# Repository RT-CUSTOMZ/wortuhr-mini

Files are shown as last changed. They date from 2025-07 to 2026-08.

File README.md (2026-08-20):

# Einleitung

Kleinere Version der Original Campuswochen Wortuhr. 
Das Buchstabenlayout dieser WortUhr ist angelehnt an das Layout, welches von Frank Meyer verwendet wird.

Der Aufbau ist nun kompatibel mit 60 LED/m WS2812B/SK6812 LED Streifen. Um das zu erreichen ist die Rahmengröße reduziert auf 35cm Innenmaß. Hierzu eignet sich zum Beispiel der IKEA SANNAHED 35x35cm Rahmen. Die Steuerplatine ist auf das wesentliche beschränkt, die Stromversorgung übernehmen zwei generische DCDC Mini-560 Netzteile. Es wird weiterhin über einen Rundbuchsenanschluss mit 19-21V eingespeist. Um die Bestellung möglichst einfach zu gestalten werden die Power und Steuerplatine auf eine gemeinsame Platine gepaneled. (Siehe Kombiplatine THT)

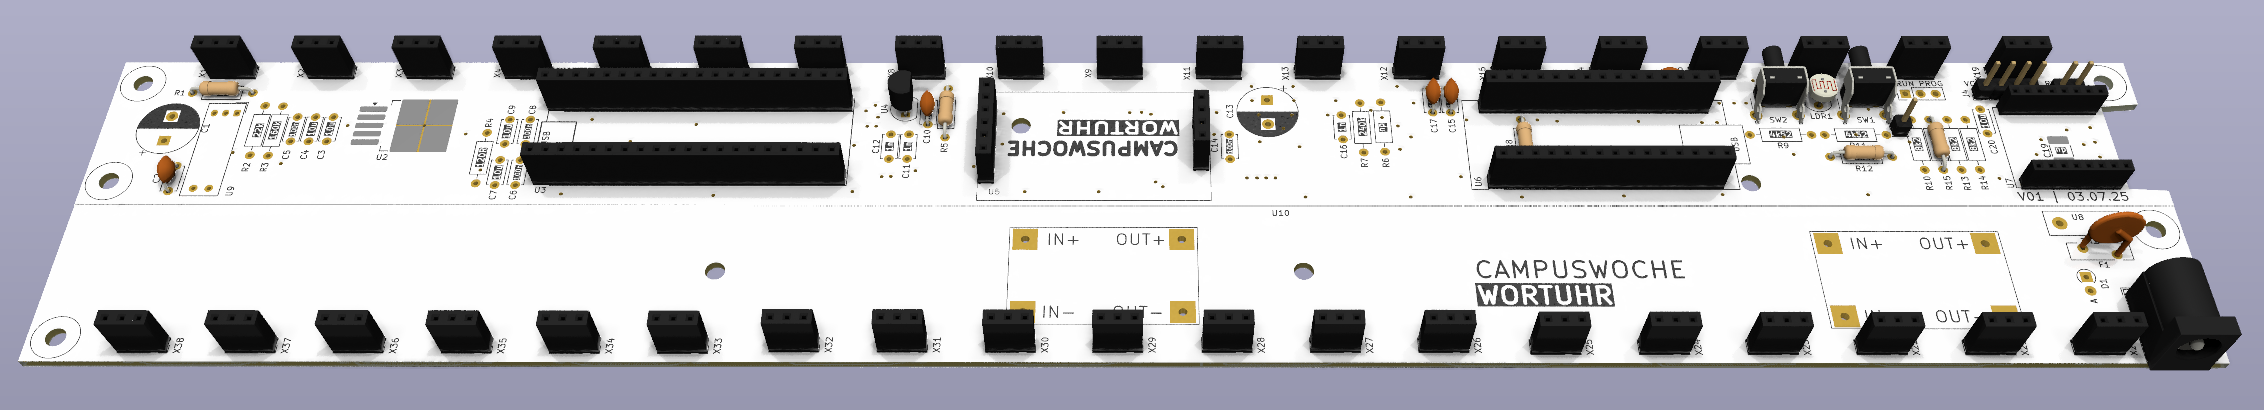
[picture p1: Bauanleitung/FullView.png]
Kombilatine


Die Software und das Layout der Matrix von Frank Meyer wurden minimal angepasst.

Originaler Artikel: https://www.mikrocontroller.net/articles/WordClock_mit_WS2812

Originaler Aufbau: https://www.mikrocontroller.net/articles/Tutorial_-_Aufbau_WordClock_mit_WS2812

# Inhaltsverzeichnis
- [Wiki](https://github.com/RT-CUSTOMZ/wortuhr-mini/wiki)
- [Bauanleitung]([/wiki/Bauanleitung](https://github.com/RT-CUSTOMZ/wortuhr-mini/wiki/Bauanleitung))
- [Hardware](https://github.com/RT-CUSTOMZ/wortuhr-mini/wiki/Hardware-Material)
- [Software](https://github.com/RT-CUSTOMZ/wortuhr-mini/wiki/Software)

Copyright (c) 2014-2019 Frank Meyer - frank(at)fli4l.de

This program is free software; you can redistribute it and/or modify it under the terms of the GNU General Public License as published by the Free Software Foundation; either version 2 of the License, or (at your option) any later version.

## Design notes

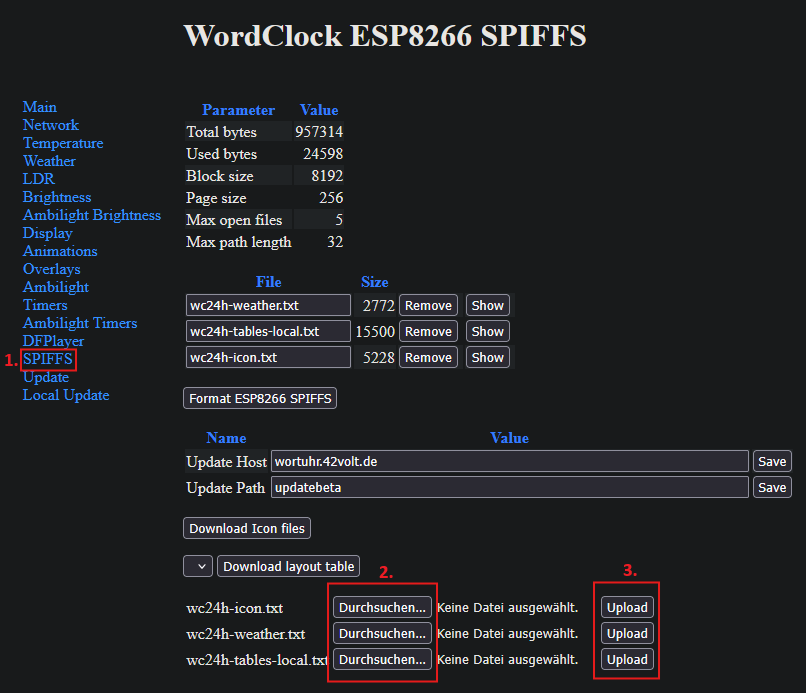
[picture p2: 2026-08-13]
Bilder/Finales_Einrichten/Wordclock_config-files.png

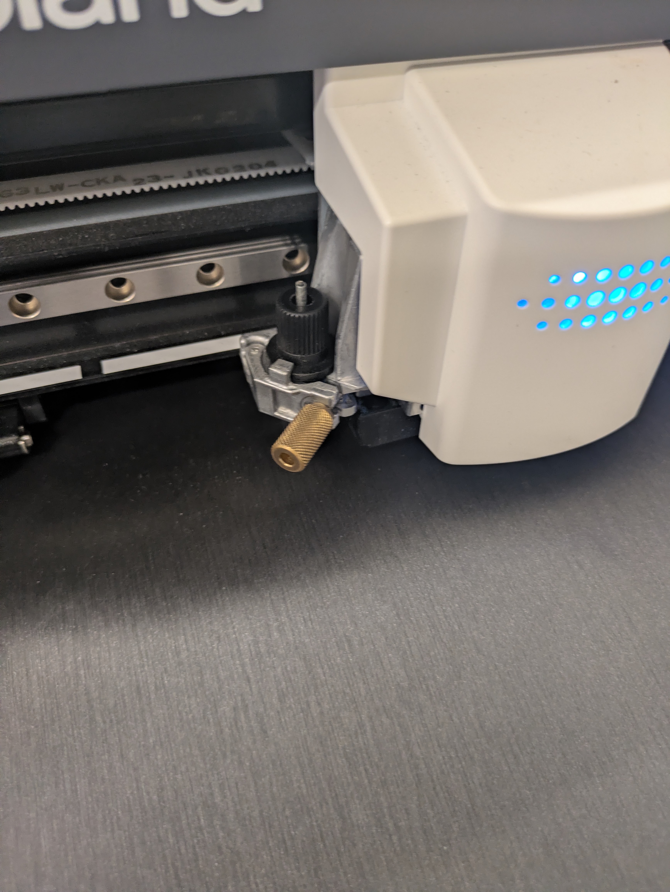
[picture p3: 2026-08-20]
Bilder/Plottern/2Klingeeinlegen.jpg

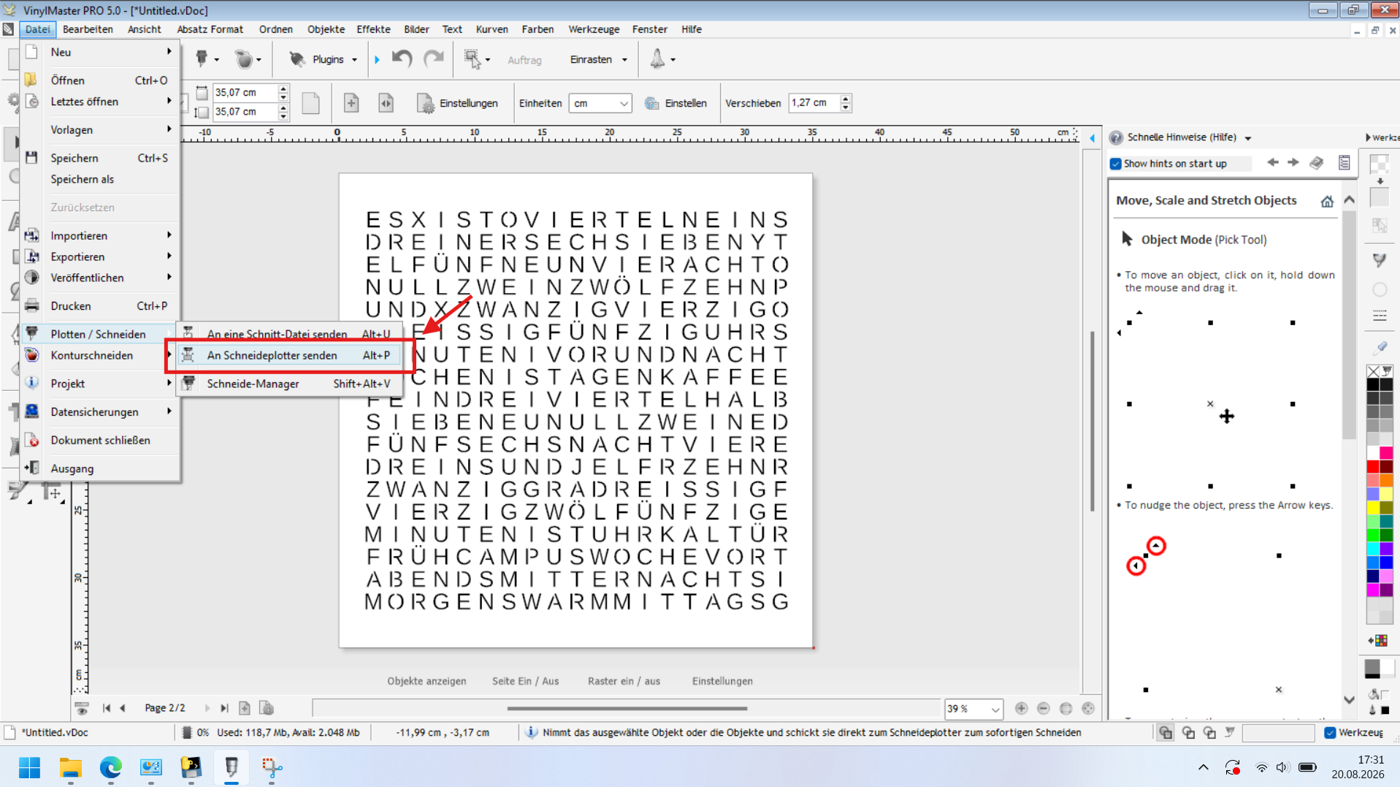
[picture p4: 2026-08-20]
Bilder/Plottern/17Plottern_6.png

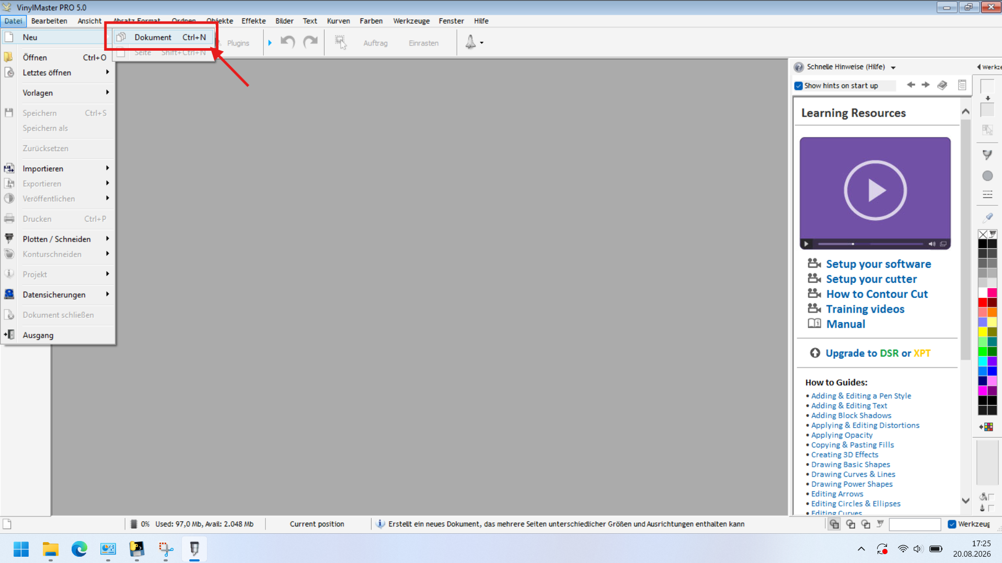
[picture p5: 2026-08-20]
Bilder/Plottern/14Plottern_3.png

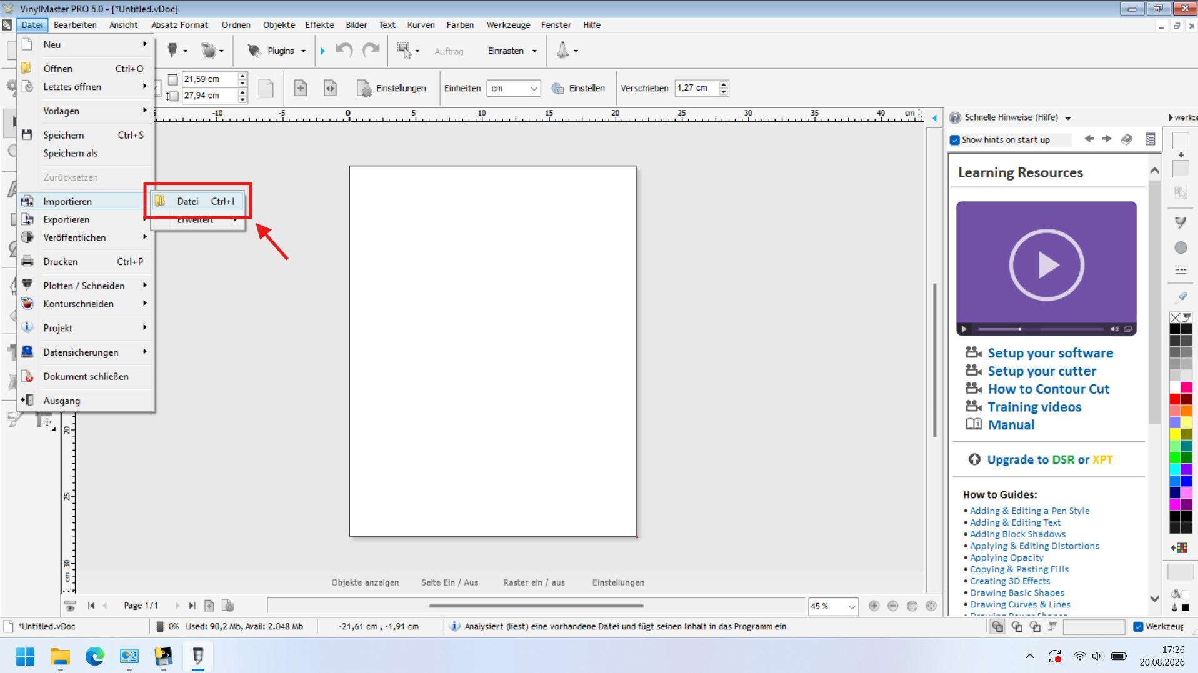
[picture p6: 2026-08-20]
Bilder/Plottern/15Plottern_4.png

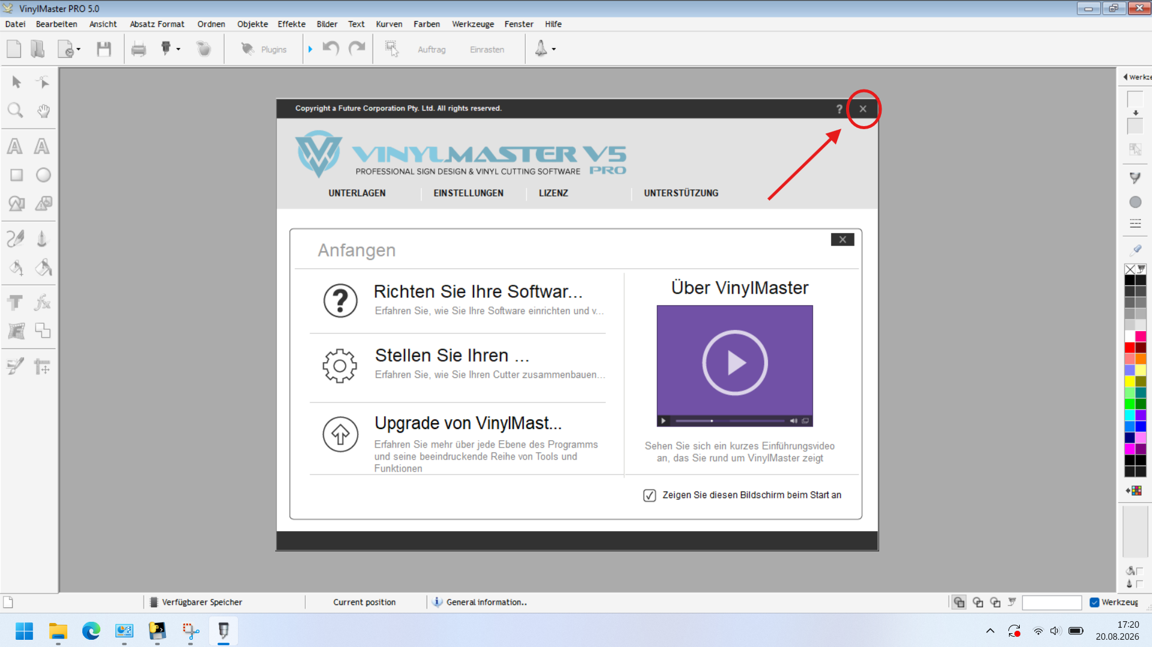
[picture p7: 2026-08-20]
Bilder/Plottern/13Plottern_2.png

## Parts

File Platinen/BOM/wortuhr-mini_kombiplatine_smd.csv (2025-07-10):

ID | Bezeichner | Footprint | Stückzahl | Bezeichnung | Anbieter und Referenz
1 | C19 | C_1812_4532Metric_Pad1.57x3.40mm_HandSolder | 1 | np | -
2 | SW1,SW2 | SW_Tactile_SPST_Angled_PTS645Vx83-2LFS | 2 | PTS645Vx83-2LFS | https://www.mouser.de/ProductDetail/CK/PTS645VL83-2-LFS?qs=rqnA19JZHeTMBWXURLIBsQ%3D%3D
3 | R4 | R_Axial_DIN0207_L6.3mm_D2.5mm_P10.16mm_Horizontal | 1 | 120R
4 | C1,C13 | CP_Radial_D10.0mm_P5.00mm | 2 | 47u
5 | U2 | TO-263-5_TabPin3 | 1 | MCP1826-ADJE/ET
6 | C3,C4,C20,C9,C7 | C_Disc_D4.7mm_W2.5mm_P5.00mm | 5 | 10u
7 | C5,C17,C14,C15,C8,C6,C2,C10,C18 | C_Disc_D4.7mm_W2.5mm_P5.00mm | 9 | 100n/X7R | https://www.mouser.de/ProductDetail/Vishay-BC-Components/K104M10X7RF5TH5?qs=ZjM2s42DDya77A69h%2FjzHg%3D%3D
8 | R2 | R_Axial_DIN0207_L6.3mm_D2.5mm_P10.16mm_Horizontal | 1 | 22k | 22k Metallschicht 1/4 Watt, 6,5mm, axial
9 | R3 | R_Axial_DIN0207_L6.3mm_D2.5mm_P10.16mm_Horizontal | 1 | 160k | 160k Metallschicht 1/4 Watt, 6,5mm, axial
10 | R12,R14,R10,R13,R5 | R_Axial_DIN0207_L6.3mm_D2.5mm_P10.16mm_Horizontal | 5 | 8k2
11 | R9,R11 | R_Axial_DIN0207_L6.3mm_D2.5mm_P10.16mm_Horizontal | 2 | 4K53
12 | J1 | TestPoint_Pad_1.0x1.0mm | 1 | Conn_01x01_Pin | -
13 | J3 | PinHeader_1x02_P2.54mm_Vertical | 1 | UART FLOATING | -
14 | X5,X4,X1,X7,X17,X3,X18,X14,X8,X16,X12,X10,X6,X13,X2,X9,X11,X15,X19 | PinHeader_1x03_P2.54mm_Vertical | 19 | Conn_01x03_Pin | https://www.mouser.de/ProductDetail/Preci-dip/801-87-010-53-001101?qs=q5BRkYolQ3jHhHUKXrMBBA%3D%3D
15 | U6 | Arduino_Nano | 1 | Arduino_Nano_Every
16 | U5 | DS3231 Module | 1 | ~ | https://eckstein-shop.de/RTC-Modul-mit-DS3231M-oder-DS3231SN-AT24C32-I2C-Echtzeituhr-mit-Batterie-fuer-Arduino-Raspberry-Pi
17 | R1,R6 | R_Axial_DIN0207_L6.3mm_D2.5mm_P10.16mm_Horizontal | 2 | np | -
18 | R8 | R_Axial_DIN0207_L6.3mm_D2.5mm_P10.16mm_Horizontal | 1 | 100k | 100k Metallschicht 1/4 Watt, 6,5mm, axial
19 | J2 | PinHeader_1x03_P2.54mm_Vertical | 1 | PROG MODE | -
20 | C16,C11,C12 | C_Disc_D4.7mm_W2.5mm_P5.00mm | 3 | 1nF/X7R | https://www.mouser.de/ProductDetail/Vishay-BC-Components/K102K15X7RF5UL2?qs=jPcpbI%252BG3FVUWYXRx4IYpg%3D%3D
21 | U7 | ESP-07 | 1 | ESP-12F | https://www.az-delivery.de/en/products/esp8266-12e
22 | U1 | DIP-6_W7.62mm_Socket_LongPads | 1 | H11L1 | https://www.mouser.de/ProductDetail/Adam-Tech/ICS-306-T?qs=FG09h9tFCuB6nMjq34Whag%3D%3D
 |  |  |  |  | https://www.mouser.de/ProductDetail/onsemi-Fairchild/H11L1TVM?qs=CaO7pQPYUzN4Nhr0JH3IIg%3D%3D
23 | U4 | TO-92_Inline | 1 | DS18B20 | https://www.reichelt.de/de/de/shop/produkt/digital_thermometer_1-wire_-_0_5_c_to-92-58169
24 | R7 | R_Axial_DIN0207_L6.3mm_D2.5mm_P10.16mm_Horizontal | 1 | 240k | 240k Metallschicht 1/4 Watt, 6,5mm, axial
25 | R15 | R_Axial_DIN0207_L6.3mm_D2.5mm_P10.16mm_Horizontal | 1 | 91R
26 | LDR1 | R_LDR_4.9x4.2mm_P2.54mm_Vertical | 1 | A 905014
27 | U3 | Bluepill | 1 | Bluepill | https://www.amazon.de/STM32F103C8T6-Minimum-Development-Learning-Importiertem/dp/B0B6BQSTSZ
 |  |  |  |  | https://www.mouser.de/ProductDetail/STMicroelectronics/STM32F103C8T6?qs=bhCVus9SdFtq6kqxsU5%2FDA%3D%3D
28 | J4 | PinHeader_1x04_P2.54mm_Vertical | 1 | UART | https://www.mouser.de/ProductDetail/Amphenol-FCI/10129378-916001BLF?qs=0lQeLiL1qybYnH80ih0s8Q%3D%3D
 |  | Netzteil Buchse |  |  | https://www.reichelt.de/de/de/shop/produkt/hohlstecker_knickschutz_aussen_5_5_mm_innen_2_1_mm-8647
 |  | DCDC Versorgung |  |  | https://www.az-delivery.de/en/products/spannungswandler-5a-8-36v-zu-1-25-32v?variant=6127498887195
 |  | LEDs |  |  | https://www.az-delivery.de/en/products/ws2812b-60-leds-m-60-pixels-m-led-strip-rgb-adressierbarer-led-streifen-mit-5050-smd-leds-ip20-schwarz-nicht-wasserdich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

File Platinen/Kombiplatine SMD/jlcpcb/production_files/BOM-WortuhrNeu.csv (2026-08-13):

Comment | Designator | Footprint | LCSC | Quantity
8k2 | R12 | R_0805_2012Metric_Pad1.20x1.40mm_HandSolder |  | 1
PTS645Vx83-2LFS | SW2 | SW_Tactile_SPST_Angled_PTS645Vx83-2LFS |  | 1
4K53 | R9 | R_0805_2012Metric_Pad1.20x1.40mm_HandSolder |  | 1
Conn_01x03_Pin | X38 | Pad LED Strip 1x03 2.54 |  | 1
Conn_01x01_Pin | J1 | PinHeader_1x01_P1.00mm_Vertical |  | 1
10u | C3 | C_1206_3216Metric_Pad1.33x1.80mm_HandSolder |  | 1
UART FLOATING | J3 | SolderJumper-2_P1.3mm_Open_RoundedPad1.0x1.5mm |  | 1
Conn_01x03_Pin | X5 | PinSocket_1x03_P2.54mm_Vertical |  | 1
10u | C4 | C_1206_3216Metric_Pad1.33x1.80mm_HandSolder |  | 1
10u | C20 | C_1206_3216Metric_Pad1.33x1.80mm_HandSolder |  | 1
100n/X7R | C17 | C_0805_2012Metric_Pad1.18x1.45mm_HandSolder |  | 1
MF-RHT100 | F1 | Fuse_Bourns_MF-RHT100 |  | 1
Arduino_Nano_Every | U6 | Arduino_Nano |  | 1
Conn_01x03_Pin | X23 | Pad LED Strip 1x03 2.54 |  | 1
Conn_01x03_Pin | X31 | Pad LED Strip 1x03 2.54 |  | 1
~ | U5 | DS3231 Module |  | 1
np | R1 | R_0805_2012Metric_Pad1.20x1.40mm_HandSolder |  | 1
Conn_01x03_Pin | X28 | Pad LED Strip 1x03 2.54 |  | 1
np | R6 | R_0805_2012Metric_Pad1.20x1.40mm_HandSolder |  | 1
Conn_01x03_Pin | X4 | PinSocket_1x03_P2.54mm_Vertical |  | 1
SL121R308 | TH1 | C_Disc_D12.0mm_W4.4mm_P7.75mm |  | 1
Conn_01x03_Pin | X1 | PinSocket_1x03_P2.54mm_Vertical |  | 1
Conn_01x03_Pin | X34 | Pad LED Strip 1x03 2.54 |  | 1
100k | R8 | R_0805_2012Metric_Pad1.20x1.40mm_HandSolder |  | 1
Conn_01x03_Pin | X7 | PinSocket_1x03_P2.54mm_Vertical |  | 1
8k2 | R14 | R_0805_2012Metric_Pad1.20x1.40mm_HandSolder |  | 1
Conn_01x03_Pin | X17 | PinSocket_1x03_P2.54mm_Vertical |  | 1
np | C19 | C_1206_3216Metric_Pad1.33x1.80mm_HandSolder |  | 1
PROG MODE | J2 | SolderJumper-3_P1.3mm_Open_RoundedPad1.0x1.5mm |  | 1
160k | R3 | R_0805_2012Metric_Pad1.20x1.40mm_HandSolder |  | 1
47u | C13 | CP_Radial_D10.0mm_P5.00mm |  | 1
Conn_01x03_Pin | X24 | Pad LED Strip 1x03 2.54 |  | 1
8k2 | R10 | R_0805_2012Metric_Pad1.20x1.40mm_HandSolder |  | 1
Conn_01x03_Pin | X3 | PinSocket_1x03_P2.54mm_Vertical |  | 1
1N5822 | D1 | D_SMC |  | 1
100n/X7R | C14 | C_0805_2012Metric_Pad1.18x1.45mm_HandSolder |  | 1
Conn_01x03_Pin | X20 | Pad LED Strip 1x03 2.54 |  | 1
Eingangsbuchse | J5 | BarrelJack_GCT_DCJ200-10-A_Horizontal |  | 1
1nF/X7R | C16 | C_0805_2012Metric_Pad1.18x1.45mm_HandSolder |  | 1
Conn_01x03_Pin | X18 | PinSocket_1x03_P2.54mm_Vertical |  | 1
Conn_01x03_Pin | X29 | Pad LED Strip 1x03 2.54 |  | 1
Conn_01x03_Pin | X14 | PinSocket_1x03_P2.54mm_Vertical |  | 1
Conn_01x03_Pin | X8 | PinSocket_1x03_P2.54mm_Vertical |  | 1
100n/X7R | C15 | C_0805_2012Metric_Pad1.18x1.45mm_HandSolder |  | 1
PTS645Vx83-2LFS | SW1 | SW_Tactile_SPST_Angled_PTS645Vx83-2LFS |  | 1
Conn_01x03_Pin | X16 | PinSocket_1x03_P2.54mm_Vertical |  | 1
Conn_01x03_Pin | X12 | PinSocket_1x03_P2.54mm_Vertical |  | 1
ESP-07 | U7 | ESP-07 |  | 1
1nF/X7R | C11 | C_0805_2012Metric_Pad1.18x1.45mm_HandSolder |  | 1
Conn_01x03_Pin | X36 | Pad LED Strip 1x03 2.54 |  | 1
10u | C9 | C_1206_3216Metric_Pad1.33x1.80mm_HandSolder |  | 1
100n/X7R | C8 | C_0805_2012Metric_Pad1.18x1.45mm_HandSolder |  | 1
10u | C7 | C_1206_3216Metric_Pad1.33x1.80mm_HandSolder |  | 1
1nF/X7R | C12 | C_0805_2012Metric_Pad1.18x1.45mm_HandSolder |  | 1
4K53 | R11 | R_0805_2012Metric_Pad1.20x1.40mm_HandSolder |  | 1
Conn_01x03_Pin | X32 | Pad LED Strip 1x03 2.54 |  | 1
DS18B20 | U4 | TO-92_Inline |  | 1
100n/X7R | C6 | C_0805_2012Metric_Pad1.18x1.45mm_HandSolder |  | 1
Generic DCDC | U8 | Converter_DCDC_RECOM_R-78B-2.0_THT |  | 1
Conn_01x03_Pin | X10 | PinSocket_1x03_P2.54mm_Vertical |  | 1
Conn_01x03_Pin | X6 | PinSocket_1x03_P2.54mm_Vertical |  | 1
Conn_01x03_Pin | X27 | Pad LED Strip 1x03 2.54 |  | 1
Conn_01x03_Pin | X13 | PinSocket_1x03_P2.54mm_Vertical |  | 1
TP582 | U9 | TP582 |  | 1
Conn_01x03_Pin | X2 | PinSocket_1x03_P2.54mm_Vertical |  | 1
100n/X7R | C2 | C_0805_2012Metric_Pad1.18x1.45mm_HandSolder |  | 1
Conn_01x03_Pin | X9 | PinSocket_1x03_P2.54mm_Vertical |  | 1
240k | R7 | R_0805_2012Metric_Pad1.20x1.40mm_HandSolder |  | 1
Conn_01x03_Pin | X11 | PinSocket_1x03_P2.54mm_Vertical |  | 1
100n/X7R | C10 | C_0805_2012Metric_Pad1.18x1.45mm_HandSolder |  | 1
22k | R2 | R_0805_2012Metric_Pad1.20x1.40mm_HandSolder |  | 1
Conn_01x03_Pin | X33 | Pad LED Strip 1x03 2.54 |  | 1
91R | R15 | R_0805_2012Metric_Pad1.20x1.40mm_HandSolder |  | 1
Conn_01x03_Pin | X30 | Pad LED Strip 1x03 2.54 |  | 1
Conn_01x03_Pin | X26 | Pad LED Strip 1x03 2.54 |  | 1
Conn_01x03_Pin | X35 | Pad LED Strip 1x03 2.54 |  | 1
Conn_01x03_Pin | X15 | PinSocket_1x03_P2.54mm_Vertical |  | 1
Conn_01x03_Pin | X25 | Pad LED Strip 1x03 2.54 |  | 1
Conn_01x03_Pin | X19 | PinSocket_1x03_P2.54mm_Vertical |  | 1
47u | C1 | CP_Radial_D10.0mm_P5.00mm |  | 1
MCP1826-ADJE/ET | U2 | TO-263-5_TabPin3 |  | 1
8k2 | R13 | R_0805_2012Metric_Pad1.20x1.40mm_HandSolder |  | 1
100n/X7R | C18 | C_0805_2012Metric_Pad1.18x1.45mm_HandSolder |  | 1
8k2 | R5 | R_0805_2012Metric_Pad1.20x1.40mm_HandSolder |  | 1
Conn_01x03_Pin | X22 | Pad LED Strip 1x03 2.54 |  | 1
100n/X7R | C5 | C_0805_2012Metric_Pad1.18x1.45mm_HandSolder |  | 1
A 905014 | LDR1 | R_LDR_4.9x4.2mm_P2.54mm_Vertical |  | 1
Conn_01x03_Pin | X37 | Pad LED Strip 1x03 2.54 |  | 1
Bluepill | U3 | Bluepill |  | 1
120R | R4 | R_0805_2012Metric_Pad1.20x1.40mm_HandSolder |  | 1
Conn_01x03_Pin | X21 | Pad LED Strip 1x03 2.54 |  | 1
UART | J4 | PinHeader_1x04_P2.54mm_Vertical |  | 1

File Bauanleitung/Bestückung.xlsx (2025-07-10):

Column1 | Placed | References | Value | Quantity
1 |  | C2, C5, C6, C8, C10, C14, C15, C17, C18 | 100nF | 9
2 |  | C3, C4, C7, C9, C20 | 10uF | 5
3 |  | C11, C12, C16 | 1nF | 3
4 |  | C1, C13 | 47uF | 2
5 |  | R5, R10, R12, R13, R14 | 8,2kΩ | 5
6 |  | R9, R11 | 4,53kΩ | 2
7 |  | R2 | 22kΩ | 1
8 |  | R3 | 160kΩ | 1
9 |  | R4 | 120Ω | 1
10 |  | R7 | 240kΩ | 1
11 |  | R8 | 100kΩ | 1
12 |  | R15 | 91Ω | 1
13 |  | U1 | IC Sockel 6 polig, 2,54mm | 1
14 |  | U2 | MCP1826-ADJE/ET Spannungswandler | 1
15 |  | U3 | Buchsenleiste 1x20, 2,54mm | 2
16 |  | U4 | DS18B20 Temperatursensor | 1
17 |  | U5 | Buchsenleiste 1x4, 2,54mm | 2
18 |  | U7 | Buchsenleiste 1x8, 2mm | 2
19 |  | SW1, SW2 | Taster gewinkelt | 2
20 |  | LDR1 | A 905014 Helligkeitssensor | 1
21 |  | J2 | Stiftleiste 1x3, 2,54mm | 1
22 |  | J3 | Stiftleiste 1x2, 2,54mm | 1
23 |  | J4 | Stiftleiste 1x4, 2,54mm | 1
24 |  | X1, X2, X3, X4, X5, X6, X7, X8, X9, X10, X11, X12, X13, X14, X15, X16, X17, X18, X19 | Buchsenleiste 1x3, 2,54mm | 19

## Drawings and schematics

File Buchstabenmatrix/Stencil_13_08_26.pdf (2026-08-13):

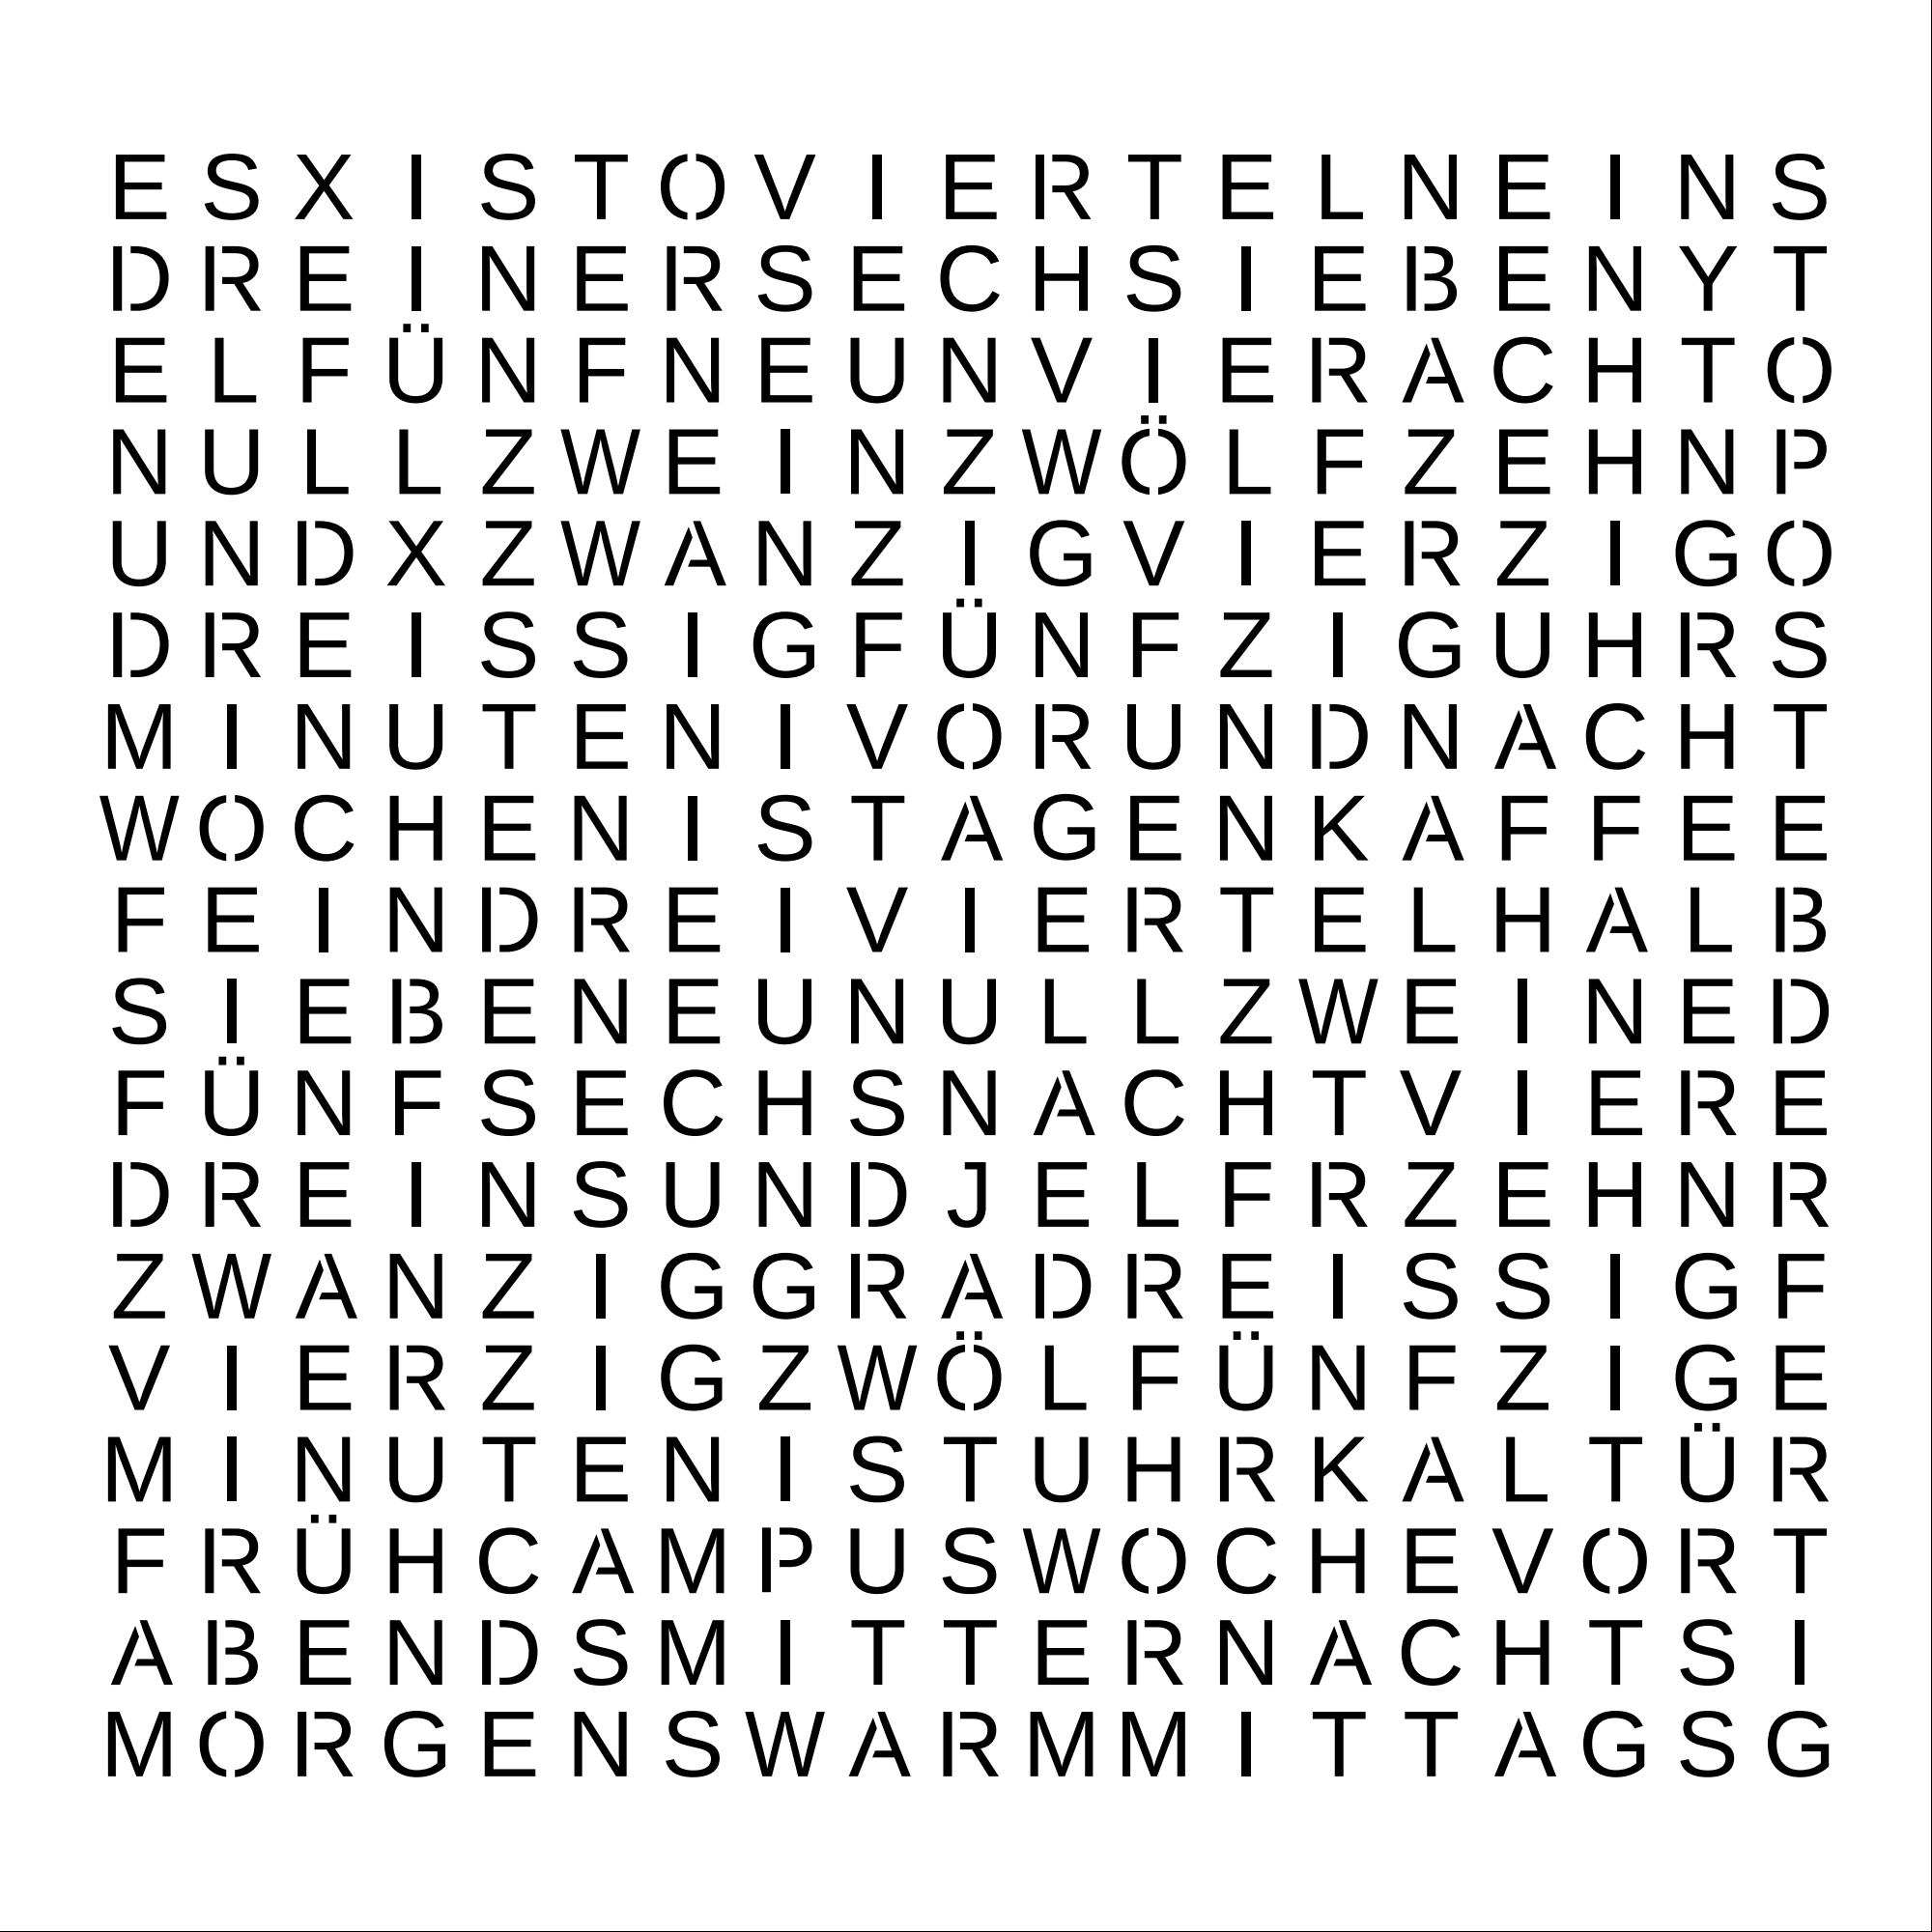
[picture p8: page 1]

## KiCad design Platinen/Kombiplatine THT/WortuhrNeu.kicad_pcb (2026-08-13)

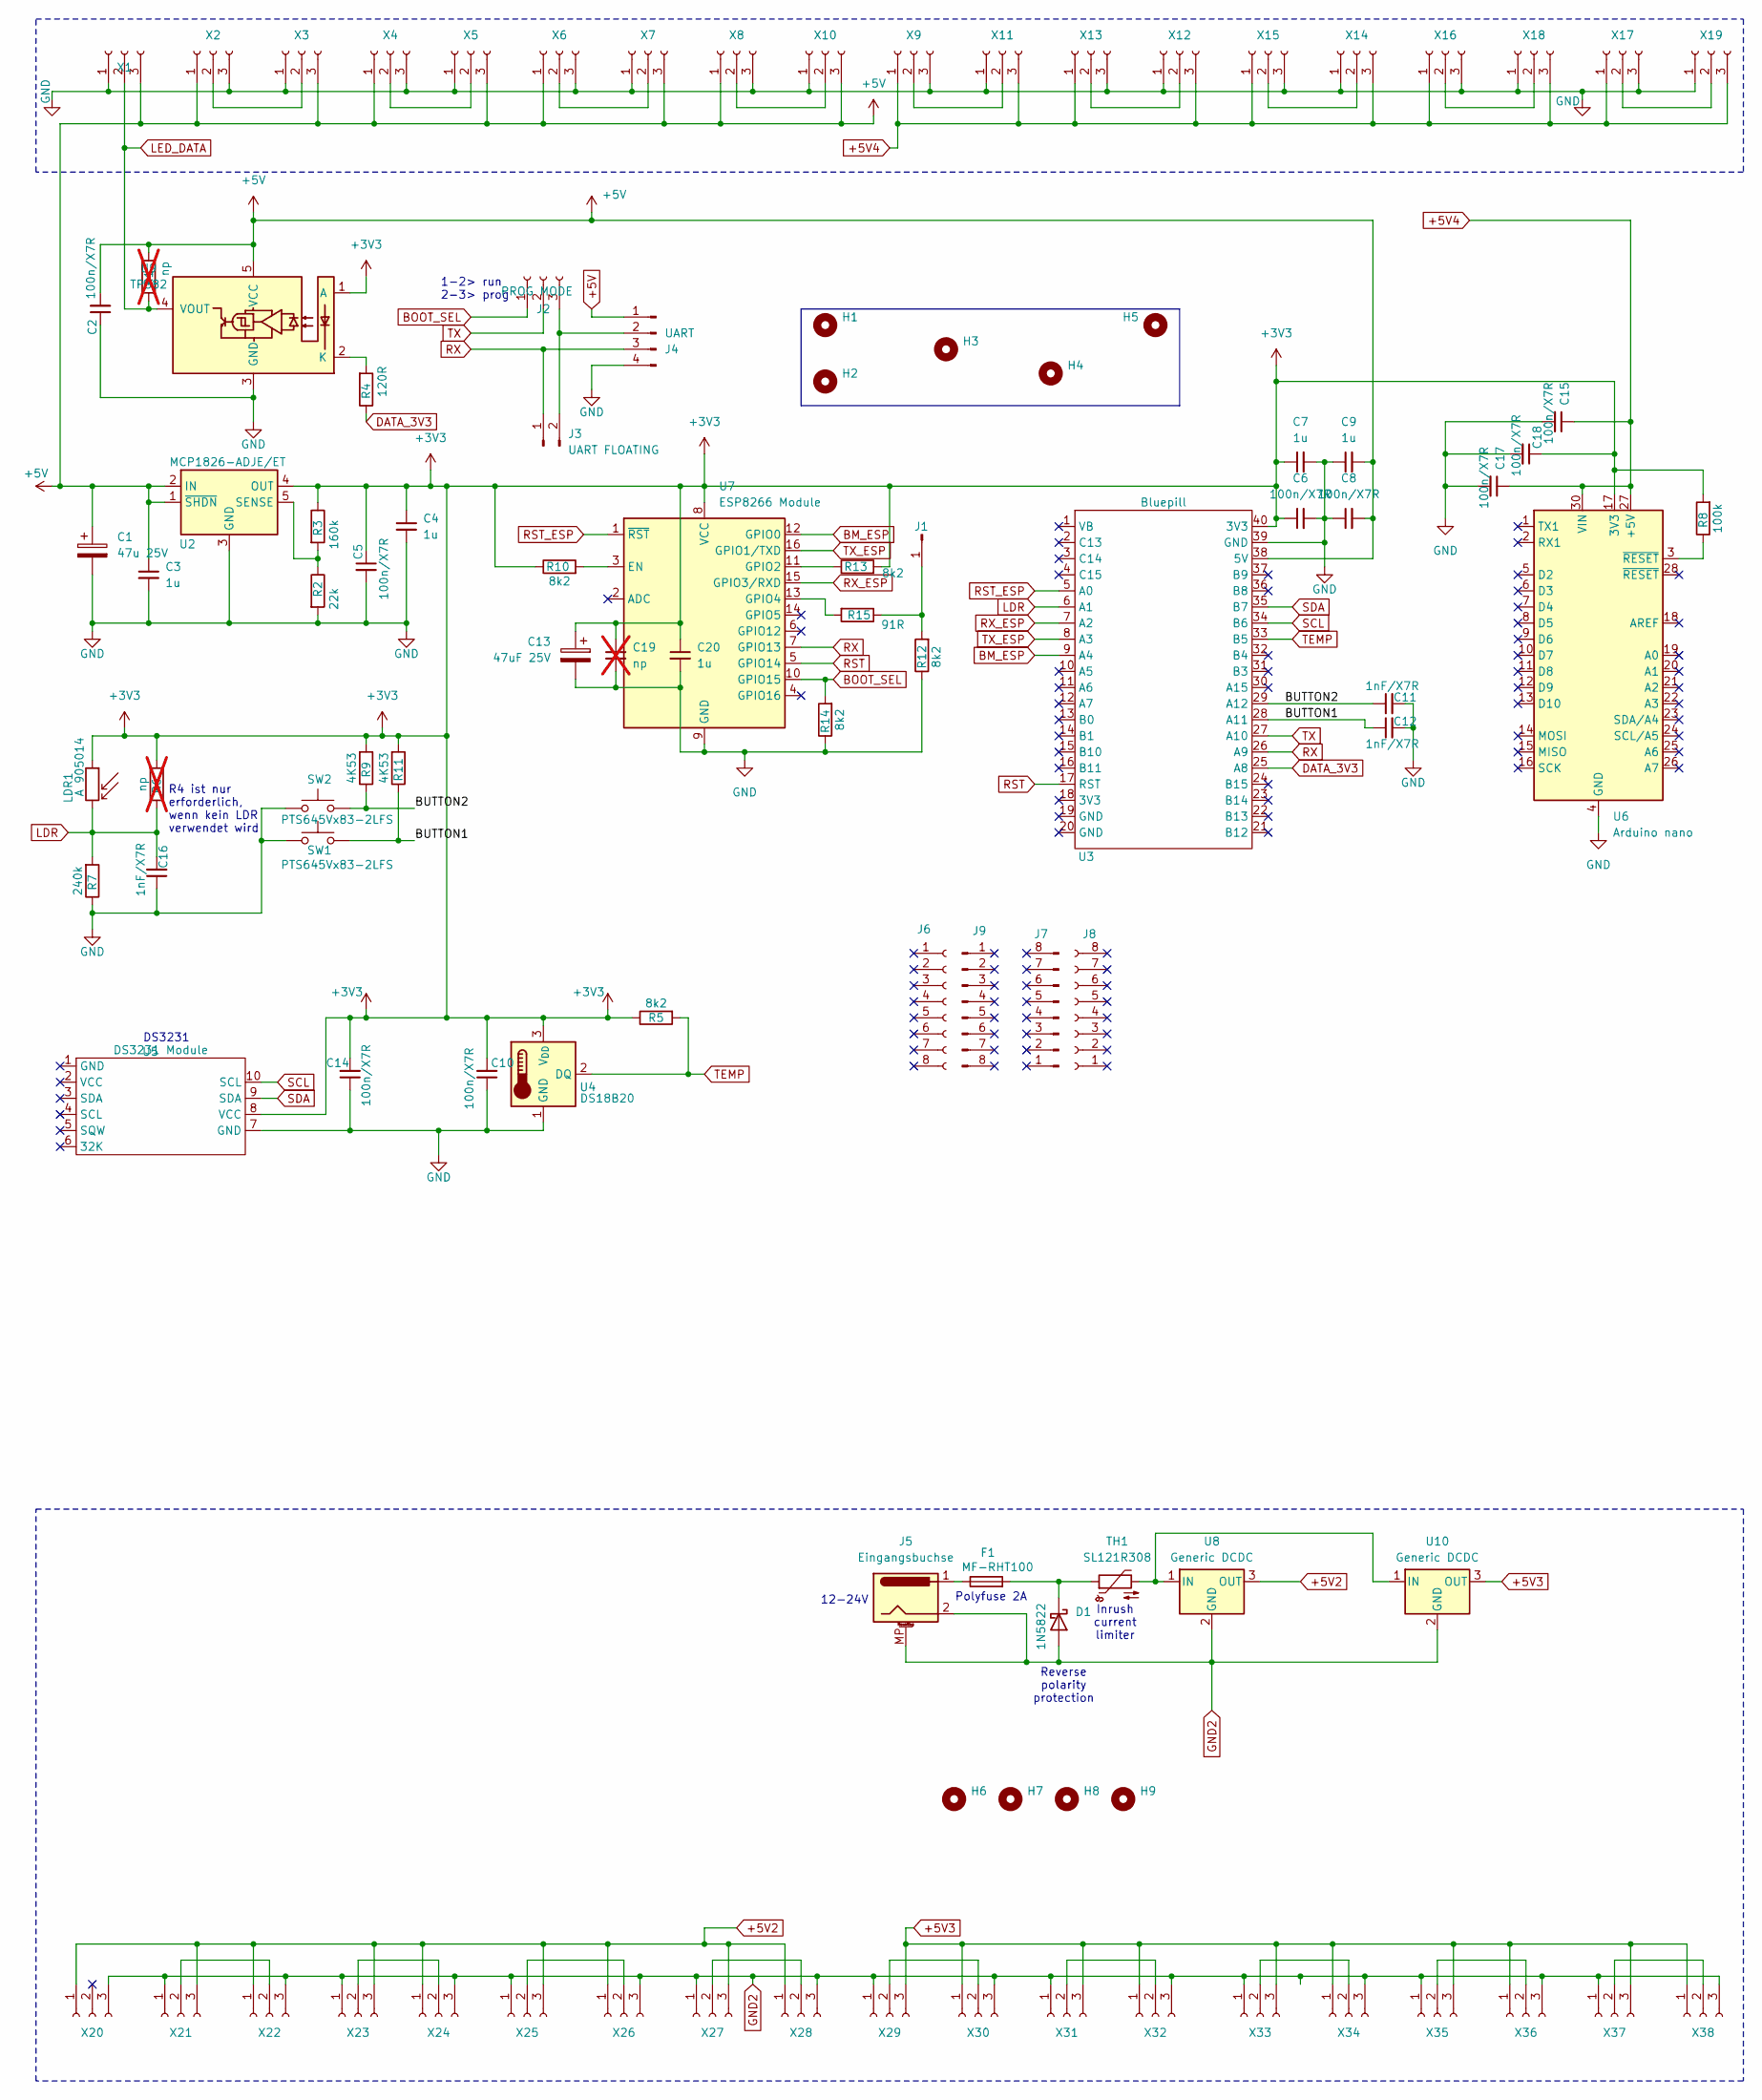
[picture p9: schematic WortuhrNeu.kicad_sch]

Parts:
C1: 47u 25V; CP_Radial_D10.0mm_P5.00mm
C2, C5, C6, C8, C10, C14, C15, C17, C18: 100n/X7R; C_Disc_D4.7mm_W2.5mm_P5.00mm
C3, C4, C7, C9, C20: 1u; C_Disc_D4.7mm_W2.5mm_P5.00mm
C11, C12, C16: 1nF/X7R; C_Disc_D4.7mm_W2.5mm_P5.00mm
C13: 47uF 25V; CP_Radial_D10.0mm_P5.00mm
C19: np; C_1812_4532Metric_Pad1.57x3.40mm_HandSolder; not fitted
D1: 1N5822; D_A-405_P2.54mm_Vertical_AnodeUp
F1: MF-RHT100; Fuse_Bourns_MF-RHT100
H1, H2, H3, H4, H5, H6, H7, H8, H9: MountingHole; MountingHole_3.2mm_M3_DIN965
J1: Conn_01x01_Pin; PinHeader_1x01_P2.54mm_Vertical
J2: PROG MODE; PinHeader_1x03_P2.54mm_Vertical
J3: UART FLOATING; PinHeader_1x02_P2.54mm_Vertical
J4: UART; PinHeader_1x04_P2.54mm_Vertical
J5: Eingangsbuchse; BarrelJack_GCT_DCJ200-10-A_Horizontal
J6, J7: Conn_01x08_Pin; PinHeader_1x08_P2.00mm_Vertical
J8, J9: Conn_01x08_Socket; PinSocket_1x08_P2.00mm_Vertical
LDR1: A 905014; R_LDR_4.9x4.2mm_P2.54mm_Vertical
R1, R6: np; R_Axial_DIN0207_L6.3mm_D2.5mm_P10.16mm_Horizontal; not fitted
R2: 22k; R_Axial_DIN0207_L6.3mm_D2.5mm_P10.16mm_Horizontal
R3: 160k; R_Axial_DIN0207_L6.3mm_D2.5mm_P10.16mm_Horizontal
R4: 120R; R_Axial_DIN0207_L6.3mm_D2.5mm_P10.16mm_Horizontal
R5, R10, R12, R13, R14: 8k2; R_Axial_DIN0207_L6.3mm_D2.5mm_P10.16mm_Horizontal
R7: 240k; R_Axial_DIN0207_L6.3mm_D2.5mm_P10.16mm_Horizontal
R8: 100k; R_Axial_DIN0207_L6.3mm_D2.5mm_P10.16mm_Horizontal
R9, R11: 4K53; R_Axial_DIN0207_L6.3mm_D2.5mm_P10.16mm_Horizontal
R15: 91R; R_Axial_DIN0207_L6.3mm_D2.5mm_P10.16mm_Horizontal
SW1, SW2: PTS645Vx83-2LFS; SW_Tactile_SPST_Angled_PTS645Vx83-2LFS
TH1: SL121R308; C_Disc_D12.0mm_W4.4mm_P7.75mm
U2: MCP1826-ADJE/ET; TO-263-5_TabPin3
U3: Bluepill
U4: DS18B20; TO-92_Inline
U5: DS3231 Module
U6: Arduino nano; Arduino_Nano
U7: ESP8266 Module; ESP-07
U8, U10: Generic DCDC; Converter_DCDC_RECOM_R-78B-2.0_THT
U9: TP582
X1, X2, X3, X4, X5, X6, X7, X8, X9, X10, X11, X12, X13, X14, X15, X16, X17, X18, X19, X20, X21, X22, X23, X24, X25, X26, X27, X28, X29, X30, X31, X32, X33, X34, X35, X36, X37, X38: Conn_01x03_Pin; PinSocket_1x03_P2.54mm_Vertical

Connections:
+3V3: C4.1, C5.1, C6.1, C7.1, C10.2, C13.1, C14.2, C18.1, C19.1, C20.1, LDR1.1, R3.1, R5.1, R6.2, R8.2, R9.2, R10.1, R11.2, R13.2, U2.4 (OUT), U3.40 (3V3), U4.3 (V_{DD}), U5.8 (VCC), U6.17 (3V3), U7.8 (VCC), U9.1 (A)
+5V: C1.1, C2.2, C3.1, C8.2, C9.2, J4.1, R1.2, U2.1 (~SHDN), U2.2 (IN), U3.38 (5V), U9.5 (VCC), X1.3, X2.1, X3.3, X4.1, X5.3, X6.1, X7.3, X8.1, X10.3
+5V2: U8.3 (OUT), X20.1, X21.3, X22.1, X23.3, X24.1, X25.3, X26.1, X27.3, X28.1
+5V3: U10.3 (OUT), X29.3, X30.1, X31.3, X32.1, X33.3, X34.1, X35.3, X36.1, X37.3, X38.1
+5V4: C15.1, C17.1, U6.27 (+5V), U6.30 (VIN), X9.1, X11.3, X12.3, X13.1, X14.3, X15.1, X16.1, X17.1, X18.3, X19.3
/BUTTON1: C12.1, R11.1, SW1.1, U3.28 (A11)
/BUTTON2: C11.1, R9.1, SW2.1, U3.29 (A12)
BM_ESP: U3.9 (A4), U7.12 (GPIO0)
BOOT_SEL: J2.1, R14.2, U7.10 (GPIO15)
DATA_3V3: R4.1, U3.25 (A8)
GND: C1.2, C2.1, C3.2, C4.2, C5.2, C6.2, C7.2, C8.1, C9.1, C10.1, C11.2, C12.2, C13.2, C14.1, C15.2, C16.1, C17.2, C18.2, C19.2, C20.2, J4.4, R2.2, R7.1, R12.1, R14.1, SW1.2, SW2.2, U2.3 (GND), U3.39 (GND), U4.1 (GND), U5.7 (GND), U6.4 (GND), U6.29 (GND), U7.9 (GND), U9.3 (GND), X1.1, X2.3, X3.1, X4.3, X5.1, X6.3, X7.1, X8.3, X9.3, X10.1, X11.1, X12.1, X13.3, X14.1, X15.3, X16.3, X17.3, X18.1, X19.1
GND2: D1.2 (A), J5.2, J5.MP (MountPin_MP), U8.2 (GND), U10.2 (GND), X20.3, X21.1, X22.3, X23.1, X24.3, X25.1, X26.3, X27.1, X28.3, X29.1, X30.3, X31.1, X32.3, X33.1, X34.3, X35.1, X36.3, X37.1, X38.3
LDR: C16.2, LDR1.2, R6.1, R7.2, U3.6 (A1)
LED_DATA: R1.1, U9.4 (VOUT), X1.2
unnamed: D1.1 (K), F1.2, TH1.1
unnamed: F1.1, J5.1
unnamed: J1.1 (Pin_1_1), R12.2, R15.1
unnamed: J2.3, J3.2, J4.2
unnamed: R8.1, U6.3 (~RESET)
unnamed: R2.1, R3.2, U2.5 (SENSE)
unnamed: R10.2, U7.3 (EN)
unnamed: R13.1, U7.11 (GPIO2)
unnamed: R15.2, U7.13 (GPIO4)
unnamed: R4.2, U9.2 (K)
unnamed: TH1.2, U8.1 (IN), U10.1 (IN)
unnamed: X2.2, X3.2
unnamed: X4.2, X5.2
unnamed: X6.2, X7.2
unnamed: X8.2, X10.2
unnamed: X9.2, X11.2
unnamed: X12.2, X13.2
unnamed: X14.2, X15.2
unnamed: X16.2, X18.2
unnamed: X17.2, X19.2
unnamed: X21.2, X22.2
unnamed: X23.2, X24.2
unnamed: X25.2, X26.2
unnamed: X27.2, X28.2
unnamed: X29.2, X30.2
unnamed: X31.2, X32.2
unnamed: X33.2, X34.2
unnamed: X35.2, X36.2
unnamed: X37.2, X38.2
RST: U3.17 (RST), U7.5 (GPIO14)
RST_ESP: U3.5 (A0), U7.1 (~RST)
RX: J3.1, J4.3, U3.26 (A9), U7.7 (GPIO13)
RX_ESP: U3.7 (A2), U7.15 (GPIO3/RXD)
SCL: U3.34 (B6), U5.10 (SCL)
SDA: U3.35 (B7), U5.9 (SDA)
TEMP: R5.2, U3.33 (B5), U4.2 (DQ)
TX: J2.2, U3.27 (A10)
TX_ESP: U3.8 (A3), U7.16 (GPIO1/TXD)

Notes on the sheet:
R4 ist nur erforderlich, wenn kein LDR verwendet wird
12-24V
DS3231
Polyfuse 2A
Reverse polarity protection
Inrush current limiter
1-2> run 2-3> prog

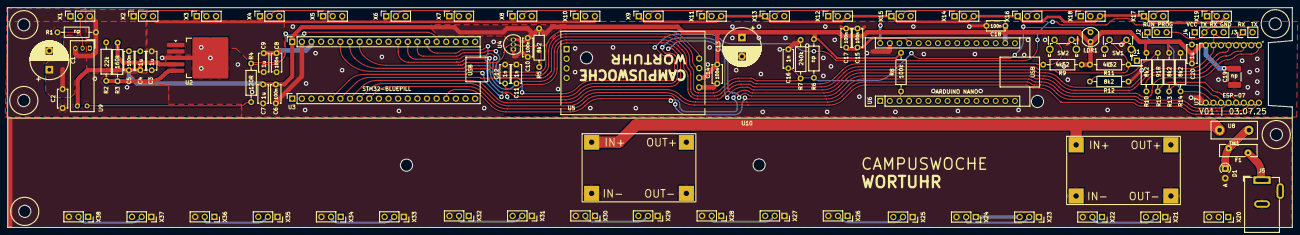
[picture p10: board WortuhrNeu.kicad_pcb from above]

Board: 2 copper layers, 339.0 x 58.0 mm, 102 parts (0 on the bottom side), 52 nets.

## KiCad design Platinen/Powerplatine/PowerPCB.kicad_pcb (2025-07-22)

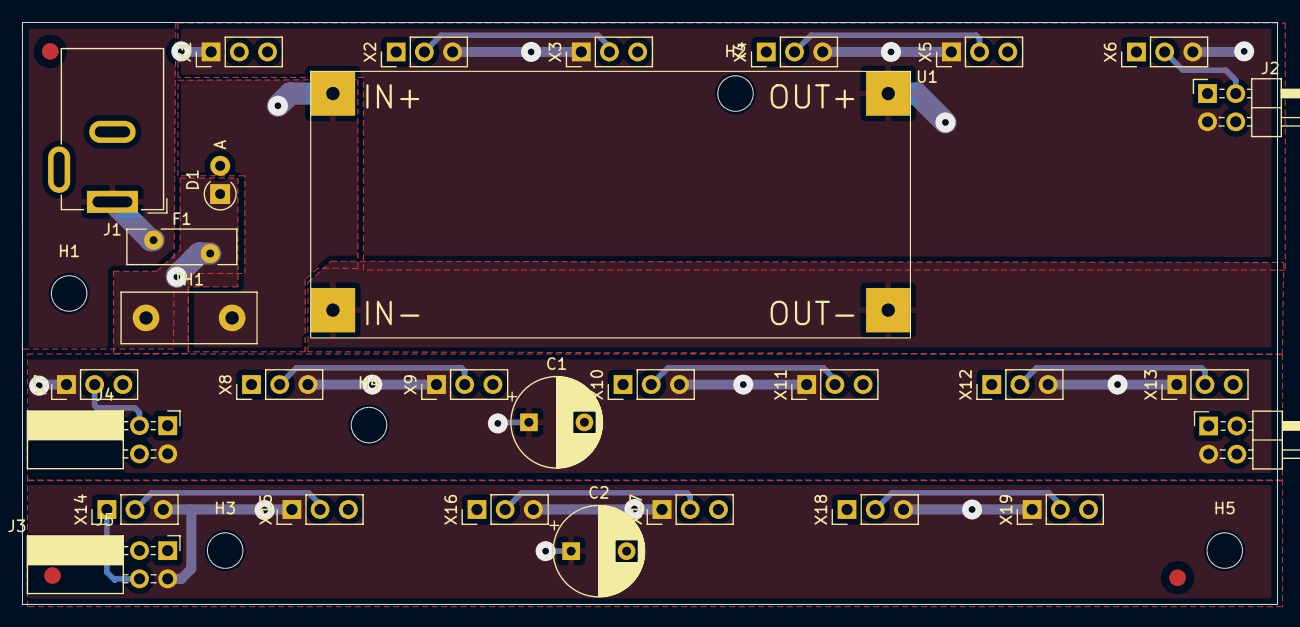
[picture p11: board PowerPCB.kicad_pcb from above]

Board: 2 copper layers, 113.0 x 52.4 mm, 38 parts (0 on the bottom side), 19 nets.

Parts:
C1, C2: 47u; CP_Radial_D8.0mm_P5.00mm
D1: 1N5822; D_A-405_P2.54mm_Vertical_AnodeUp
F1: MF-RHT100; Fuse_Bourns_MF-RHT100
FID1, FID2, FID3: Fiducial; Fiducial_1.5mm_Mask3mm
H1, H2, H3, H4, H5: MountingHole; MountingHole_3.2mm_M3_DIN965
J1: Eingangsbuchse; BarrelJack_GCT_DCJ200-10-A_Horizontal
J2, J3: Conn_01x03_Pin; PinHeader_2x02_P2.54mm_Horizontal
J4, J5: Conn_01x03_Socket; PinSocket_2x02_P2.54mm_Horizontal
TH1: SL121R308; C_Disc_D12.0mm_W4.4mm_P7.75mm
U1: Generic DCDC; Converter_DCDC_RECOM_R-78B-2.0_THT
X1, X2, X3, X4, X5, X6, X7, X8, X9, X10, X11, X12, X13, X14, X15, X16, X17, X18, X19: Conn_01x03_Pin; PinHeader_1x03_P2.54mm_Vertical

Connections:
+5V: J2.3, U1.3 (OUT), X1.1, X2.3, X3.1, X4.3, X5.1, X6.3
+5V2: C1.1, J3.3, J4.3, X7.1, X8.3, X9.1, X10.3, X11.1, X12.3, X13.1
+5V3: C2.1, J5.3, X14.3, X15.1, X16.3, X17.1, X18.3, X19.1
GND: D1.2 (A), J1.2, J1.MP (MountPin), J2.1, U1.2 (GND), X1.3, X2.1, X3.3, X4.1, X5.3, X6.1
GND2: C1.2, J3.1, J4.1, X7.3, X8.1, X9.3, X10.1, X11.3, X12.1, X13.3
GND3: C2.2, J5.1, X14.1, X15.3, X16.1, X17.3, X18.1, X19.3
unnamed: D1.1 (K), F1.2, TH1.1
unnamed: F1.1, J1.1
unnamed: J2.2, X6.2
unnamed: J4.2, X7.2
unnamed: TH1.2, U1.1 (IN)
unnamed: X2.2, X3.2
unnamed: X4.2, X5.2
unnamed: X8.2, X9.2
unnamed: X10.2, X11.2
unnamed: X12.2, X13.2
unnamed: X14.2, X15.2
unnamed: X16.2, X17.2
unnamed: X18.2, X19.2

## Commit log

2025-07-10 Changed file structure
    [WortuhrNeu.kicad_pcb, WortuhrNeu.kicad_sch]
2025-07-14 Added power PCB/protection circuits
    [PowerPCB.kicad_pcb, PowerPCB.kicad_sch, WortuhrNeu.kicad_pcb]
2025-07-14 Changed pins to sockets, added image
    [PowerPCB.kicad_pcb]
2025-07-14 added letter matrix pdf v1
    [PowerPCB.kicad_pcb, PowerPCB.kicad_sch, wortuhr-mini.csv]
2025-07-19 Adjusted letter matrix and added stencil verśion
    [PowerPCB-BOT.gbr, PowerPCB-B_Cu.gbr, PowerPCB-Eco1_User.gbr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]
2025-07-19 added file for base plate layout/laser
2025-07-20 added horizonzal and vertical lasercut pieces
2025-07-22 added trotec template
    [PowerPCB-BOT.gbr, PowerPCB-B_Cu.gbr, PowerPCB-Eco1_User.gbr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]
2025-07-24 added baseplate
    [PowerPCB-B_Cu.gbr, PowerPCB-B_Fab.gbr, PowerPCB-Eco1_User.gbr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]
2025-07-24 ADJUSTED CUTS FOR BASE PLATE
2026-05-28 Merged major changes for this years wordclock (#5)
    * Combied pcbs, added smd version
    * Implement some of the changes requested in issue 1
    * Changes to Kombiplatine THT
    ---------
    [PowerPCB-BOT.gbr, PowerPCB-B_Cu.gbr, PowerPCB-B_Fab.gbr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]
2026-05-28 Switched gpio4&5 on the esp for both boards
    [WortuhrNeu.kicad_pcb, WortuhrNeu.kicad_sch]
2026-05-28 Moved J1 closer to STM32 for OTA cable(SMD)
    [WortuhrNeu.kicad_pcb]
2026-08-13 Implemented changes made for 2026 version, added second dcdc
    [BOM-WortuhrNeu.csv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]
2026-08-13 New renders of the PCB for the Readme
2026-08-13 Edited descriptors in Kicad and updated iBom
    [WortuhrNeu.kicad_pcb, WortuhrNeu.kicad_sch]
